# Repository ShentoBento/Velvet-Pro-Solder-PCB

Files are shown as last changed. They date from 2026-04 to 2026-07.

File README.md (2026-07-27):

# Velvet Pro Solder PCB

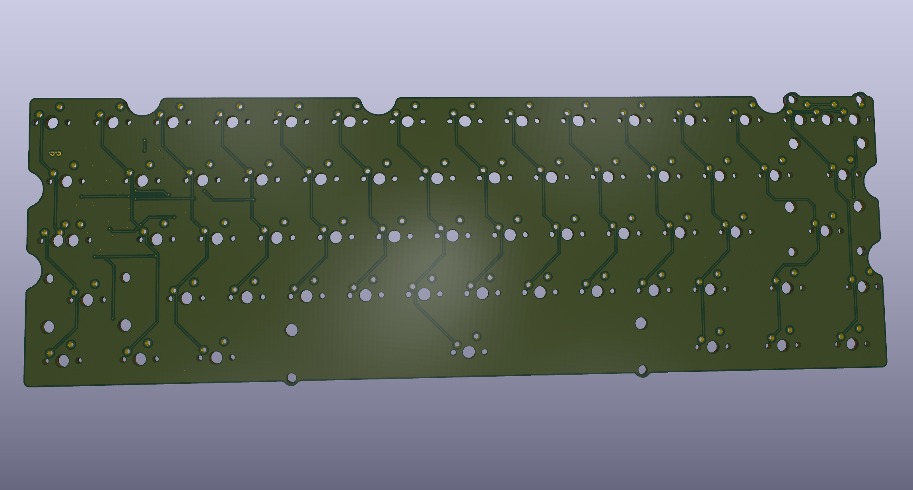
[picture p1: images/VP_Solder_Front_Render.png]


A solder PCB designed to fit the Velvet Pro keyboard by Ampersandy.

Firmware: https://github.com/ShentoBento/Velvet-Pro-PCB-Firmware

---

## Specs

- Solder
- MCU: STM32F072CBTx
- JST SH 4-pin connector (for C3 Unified Daughterboards)
- Fixed ANSI enter
- Fixed 7u bottom row
- Fixed split right shift
- Stepped or full caps lock
- Split or full backspace
- VIA and Vial compatible (via the firmware linked above)

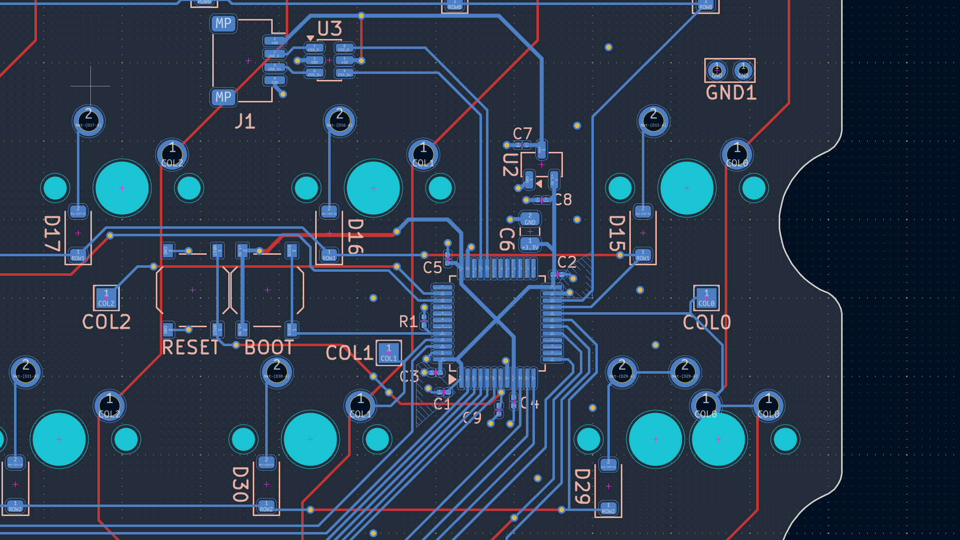
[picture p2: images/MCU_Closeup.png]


---

## Requirements

- **KiCad 10** or newer. Earlier versions will not open these files.
- Nothing else. All symbols, footprints, and 3D models used by this project are
  included in this repo — no external libraries to install, no PCM packages,
  no library paths to configure.

---

## Opening the project

1. Clone or download this repo.
2. Open `VP_Solder_KiCad/VP_Solder.kicad_pro` in KiCad.

The library paths are stored relative to the project folder, so the repo works
from any location on any operating system. If KiCad reports missing symbols or
footprints, the most likely cause is that the `shentobento_kicad_library/`
folder was not cloned alongside `VP_Solder_KiCad/`.

---

## What's in this repo

### `VP_Solder_KiCad/`

The KiCad project. These are the files you edit.

| File | What it is |
|---|---|
| `VP_Solder.kicad_pro` | Project file — **open this one** |
| `VP_Solder.kicad_sch` | Schematic |
| `VP_Solder.kicad_pcb` | Board layout |
| `fp-lib-table`, `sym-lib-table` | Point KiCad at the bundled library |
| `fabrication-toolkit-options.json` | Settings for the JLCPCB fabrication plugin |

### `VP_Solder_KiCad/production/`

Ready-to-order manufacturing files, generated with the JLCPCB Fabrication Toolkit plugin.

| File | Upload it to |
|---|---|
| `VP_Solder.zip` | JLCPCB's gerber upload — this is the board itself |
| `bom.csv` | Assembly service (which parts) |
| `positions.csv` | Assembly service (where they go) |

If you modify the design, **regenerate these** rather than reusing them. Stale
production files that don't match the current board are how wrong PCBs get
manufactured.

### `shentobento_kicad_library/`

Every symbol and footprint this project uses, in one place.

- `shentobento.kicad_sym` — all symbols
- `shentobento.pretty/` — all footprints
- `3dmodels/` — 3D models for the parts that need them

Symbols come with their footprints pre-assigned, so dragging a part into a
schematic gives you a working part with no footprint assignment step.

This folder is self-contained and can be copied into other keyboard projects.

### `reference files and images`

Not needed to build the board — useful if you're modifying the layout.

- `Plate_File_No_Flex_Cuts.dxf` / `Plate_File_with_Flex_Cuts.dxf` — the official
  Velvet Pro plate files, used to align switch and stabilizer positions
- `VP PCB DXF.dxf` — the official board outline, thanks to Andykit
- Various images of the PCB and schematic

---

## Credits and licenses

Keyboard footprints and symbols are derived from
[marbastlib](https://github.com/ebastler/marbastlib) by ebastler, licensed under
CERN-OHL-P v2. See `shentobento_kicad_library/LICENSE-marbastlib.txt`.

Generic footprints (passives, SOT-23, LQFP-48, JST SH, test points) are copied
from the KiCad standard libraries.

Modifications made to third-party files are recorded in
`shentobento_kicad_library/NOTICE.md`.

The Velvet Pro case and plate files are the work of Ampersandy.

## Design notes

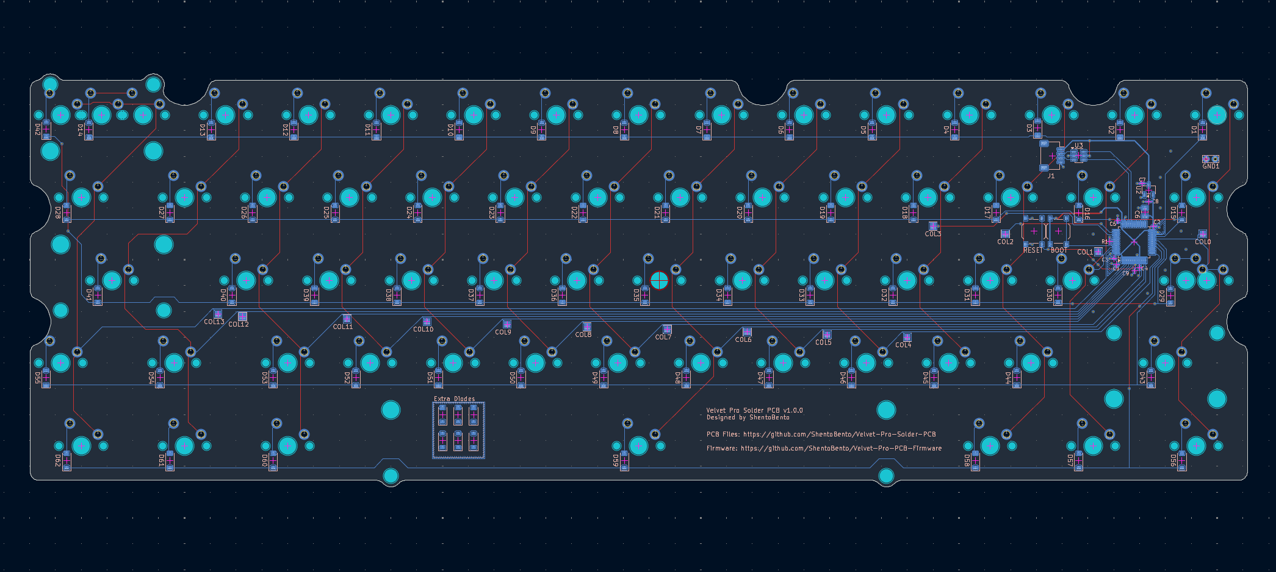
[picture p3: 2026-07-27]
images/Back_2.png

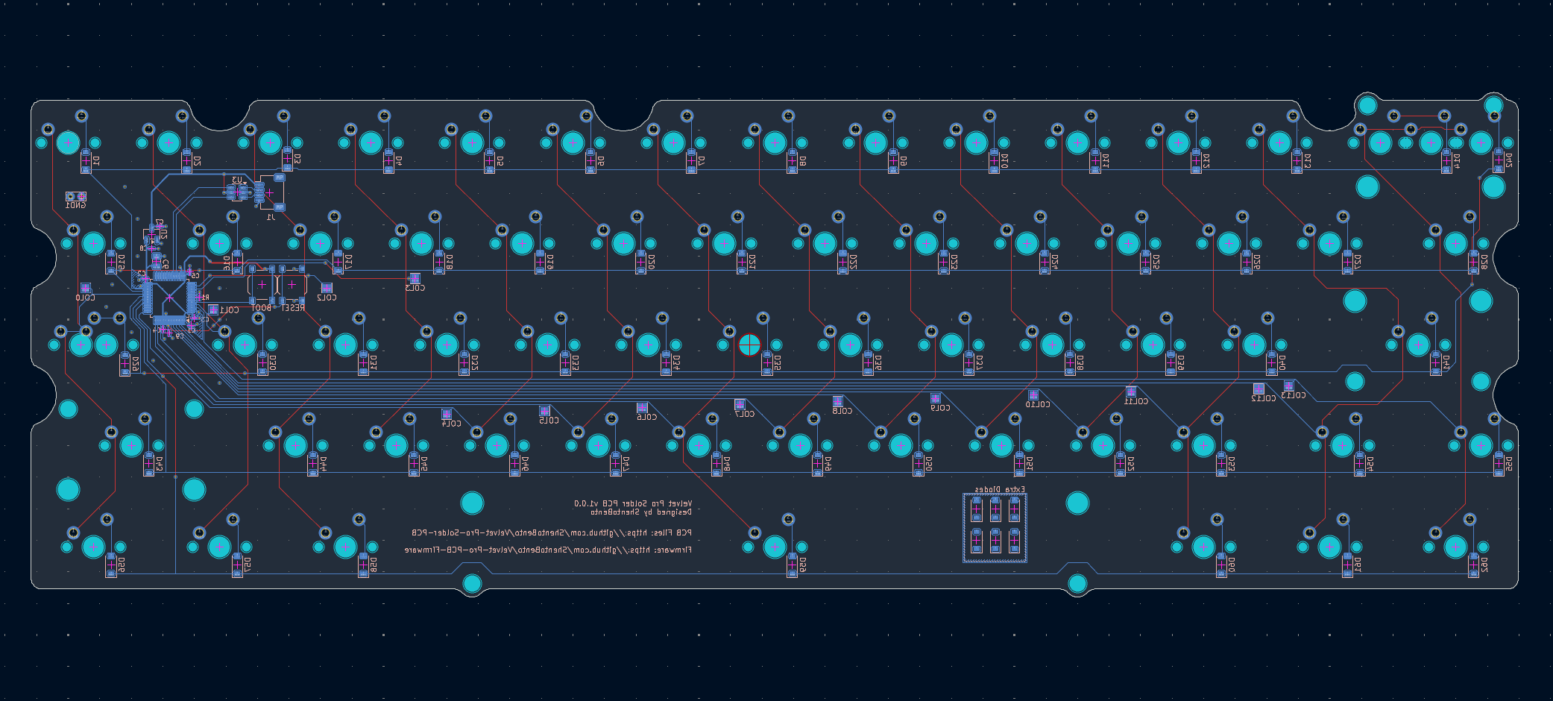
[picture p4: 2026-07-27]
images/Front_2.png

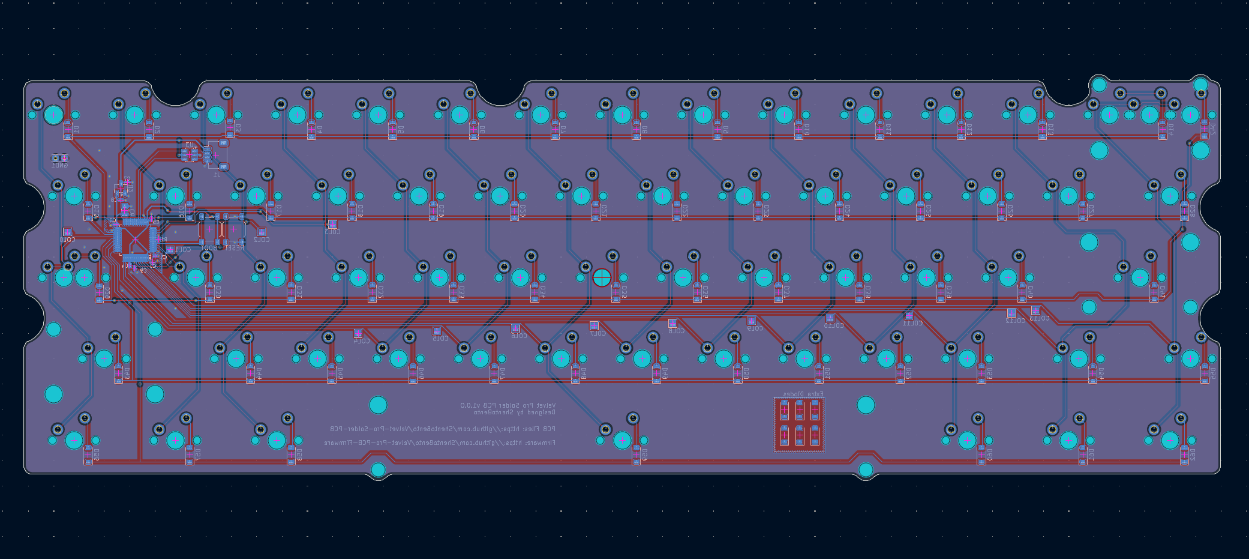
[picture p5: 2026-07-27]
images/Front_1.png

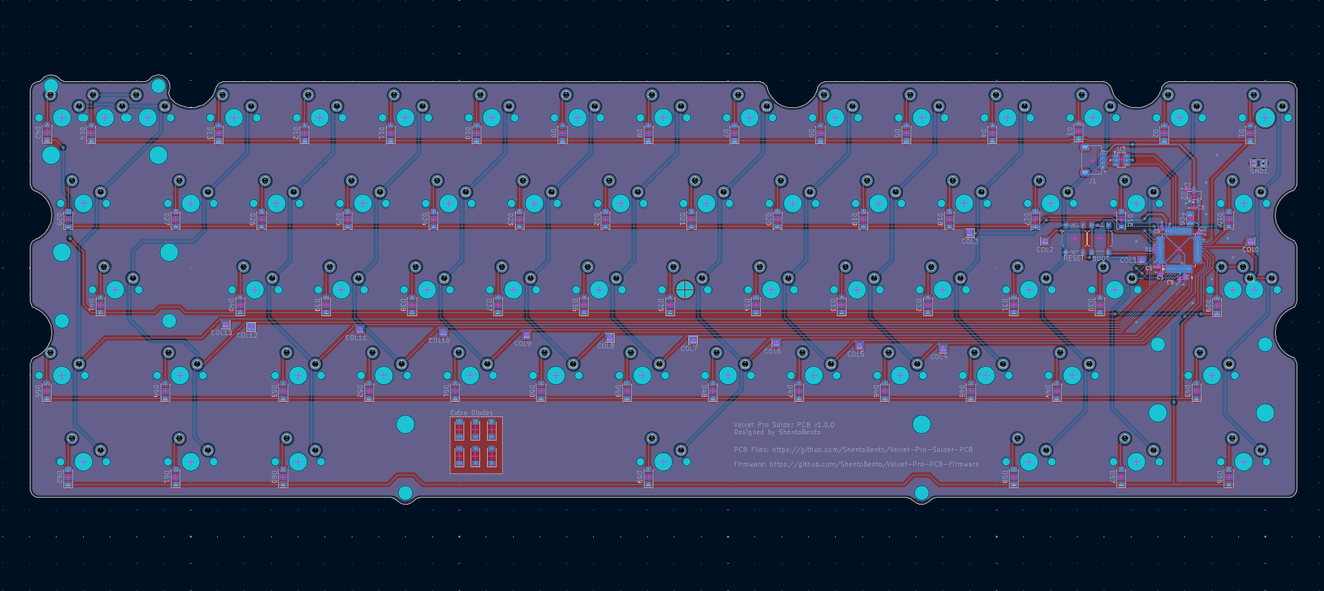
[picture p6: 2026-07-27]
images/Back_1.png

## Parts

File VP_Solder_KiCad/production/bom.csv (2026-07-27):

Designator | Footprint | Quantity | Value | LCSC Part #
C1, C2, C3, C4, C5 | 0201 | 5 | 100nF
C6 | 0805 | 1 | 10uF
C7, C8 | 0201 | 2 | 1uF
C9 | 0201 | 1 | 0.1uF
COL0, COL1, COL10, COL11, COL12, COL13, COL2, COL3, COL4, COL5, COL6, COL7, COL8, COL9 | TestPoint_Pad_1.5x1.5mm | 14 | TestPoint
D1, D10, D11, D12, D13, D14, D15, D16, D17, D18, D19, D2, D20, D21, D22, D23, D24, D25, D26, D27, D28, D29, D3, D30, D31, D32, D33, D34, D35, D36, D37, D38, D39, D4, D40, D41, D42, D43, D44, D45, D46, D47, D48, D49, D5, D50, D51, D52, D53, D54, D55, D56, D57, D58, D59, D6, D60, D61, D62, D63, D64, D65, D66, D67, D68, D7, D8, D9 | D_SOD-123 | 68 | 1N4148
GND1 | TestPoint_Bridge_Pitch2.0mm_Drill0.7mm | 1 | TestPoint
J1 | JST_SH_1x04 | 1 | Conn_01x04
KC_0, KC_1, KC_2, KC_3, KC_4, KC_5, KC_6, KC_7, KC_8, KC_9, KC_A1, KC_B1, KC_BKSP1, KC_BKSP2, KC_BSLS2, KC_C1, KC_COMM1, KC_D1, KC_DOT1, KC_E1, KC_ENT1, KC_EQL1, KC_ESC1, KC_F1, KC_G1, KC_H1, KC_I1, KC_J1, KC_K1, KC_L1, KC_LBRC1, KC_LGUI1, KC_LSFT1, KC_M1, KC_MINS1, KC_MO1, KC_N1, KC_O1, KC_P1, KC_Q1, KC_QUOT1, KC_R1, KC_RBRC1, KC_RGUI1, KC_RSFT1, KC_S1, KC_SCLN1, KC_SLSH1, KC_SPC1, KC_T1, KC_U1, KC_V1, KC_W1, KC_X1, KC_Y1, KC_Z1 | SW_MX_1u | 56 | MX_SW_solder
KC_BSLS1, KC_LALT1, KC_LCTL1, KC_RALT1, KC_RCTL1, KC_TAB1 | SW_MX_1.5u | 6 | MX_SW_solder
KC_CAPS1 | SW_MX_1.75u | 1 | MX_SW_solder
KC_STEP1 | SW_MX_1.75u_STEPPED_1.25 | 1 | MX_SW_solder
R1 | 0201 | 1 | 10k
SW1, SW2 | SW_Push_Reset_Bootloader | 2 | SW_Push
U1 | MCU_STM32F072CBTx | 1 | STM32F072CBTx
U2 | SOT-23-3 | 1 | XC6206PxxxMR
U3 | SOT-23-6 | 1 | USBLC6-2SC6

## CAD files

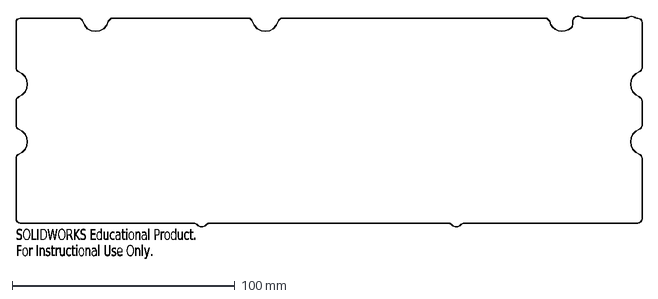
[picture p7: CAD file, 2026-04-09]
Other files (mainly for reference)/Velvet_Pro_PCB_outline.DXF
SOLIDWORKS Educational Product.
For Instructional Use Only.

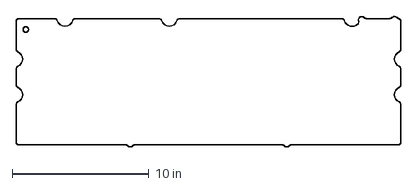
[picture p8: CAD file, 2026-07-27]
reference/Velvet_Pro_PCB_outline.dxf
28.1 x 9.55 in

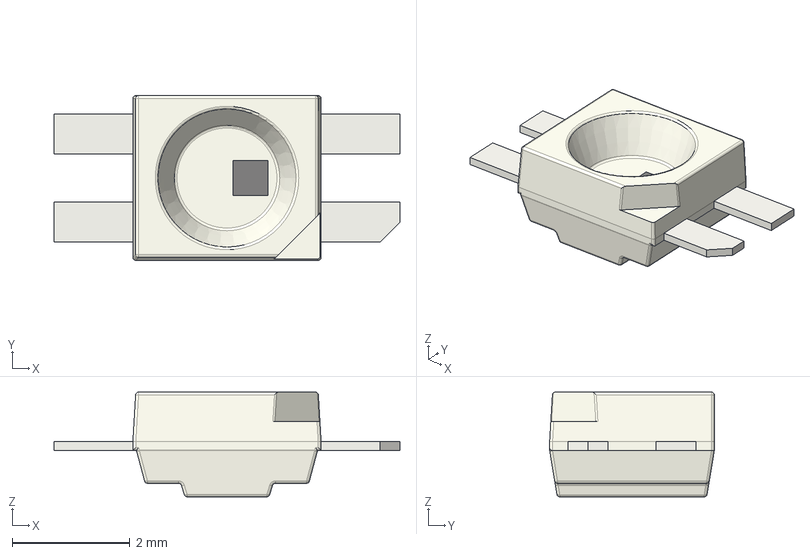
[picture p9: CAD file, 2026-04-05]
shentobento_kicad_library/3dmodels/LED_SK6812MINI-E.step
5.88 x 2.80 x 1.78 mm

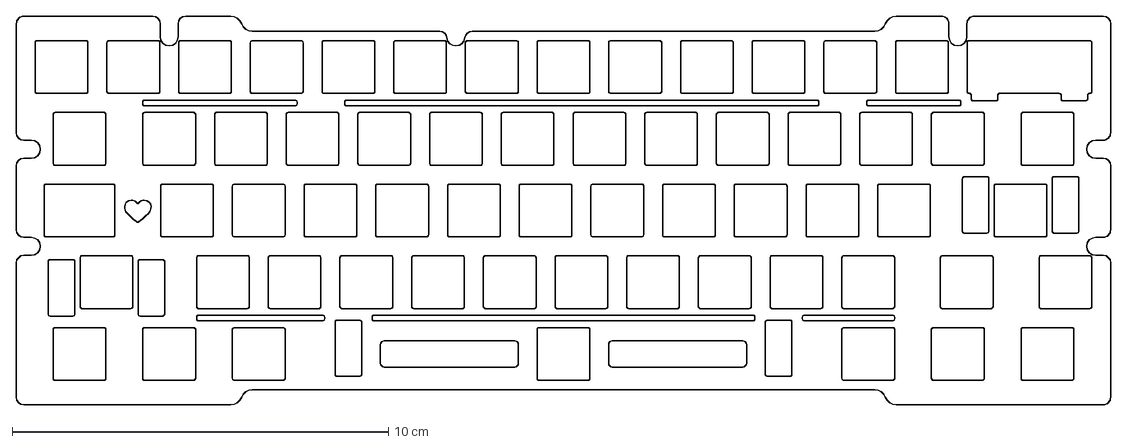
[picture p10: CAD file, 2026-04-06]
reference/Plate_File_with_Flex_Cuts.dxf
29.1 x 10.3 cm

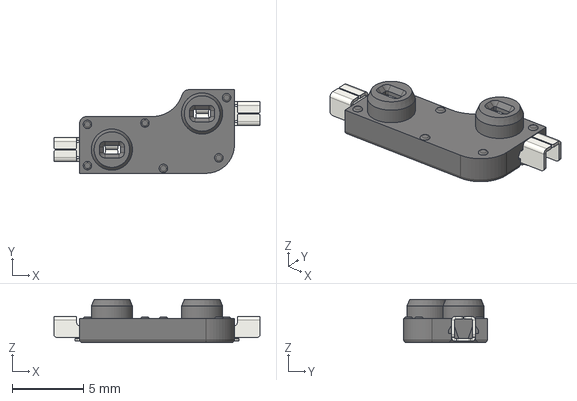
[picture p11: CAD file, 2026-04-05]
shentobento_kicad_library/3dmodels/HS_CPG151101S11_MX.step
14.5 x 5.89 x 3.05 mm
Contact x 2

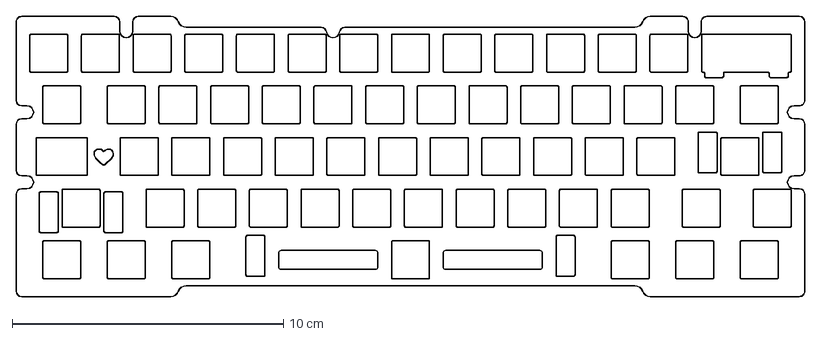
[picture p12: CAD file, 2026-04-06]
reference/Plate_File_No_Flex_Cuts.dxf
29.1 x 10.3 cm

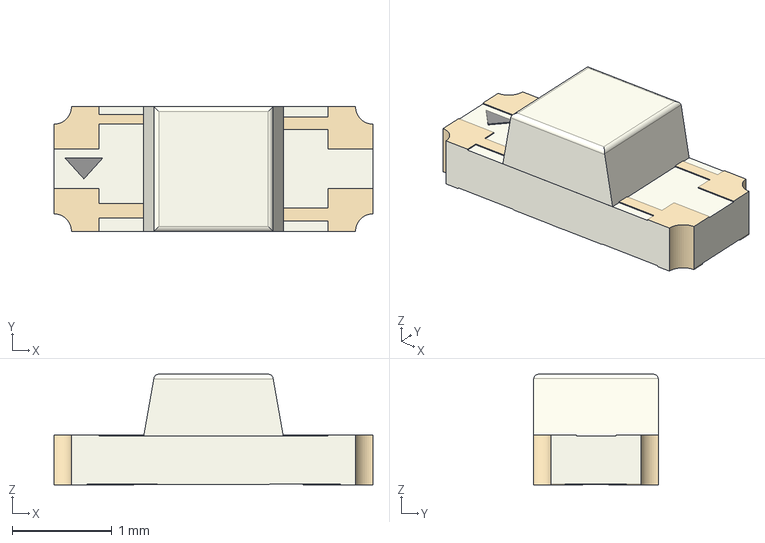
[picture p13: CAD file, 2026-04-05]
shentobento_kicad_library/3dmodels/LED_MHT151RGBCT.step
3.20 x 1.25 x 1.11 mm

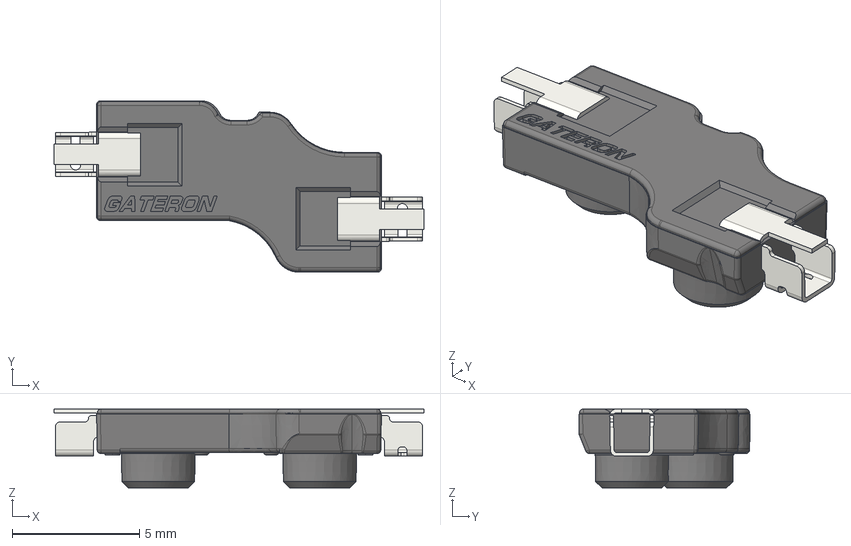
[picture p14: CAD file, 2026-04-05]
shentobento_kicad_library/3dmodels/HS_KS-2P02B01-01_MX.step
14.6 x 6.74 x 3.10 mm

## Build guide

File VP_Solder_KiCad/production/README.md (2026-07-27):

# How to order this PCB from JLCPCB

You do **not** need KiCad for this. Everything you need is in
`VP_Solder_KiCad/production/`.

---

## What you need

| File | What it's for |
|---|---|
| `VP_Solder.zip` | The board itself. Required. |
| `bom.csv` | Which parts to solder on. Only needed for assembly. |
| `positions.csv` | Where those parts go. Only needed for assembly. |

---

## Ordering from JLCPCB with Assembly

**Estimated Costs:** $20-30/PCB shipped to US (tariffs included)
**Fullfillment Time:** Around 2-3 weeks

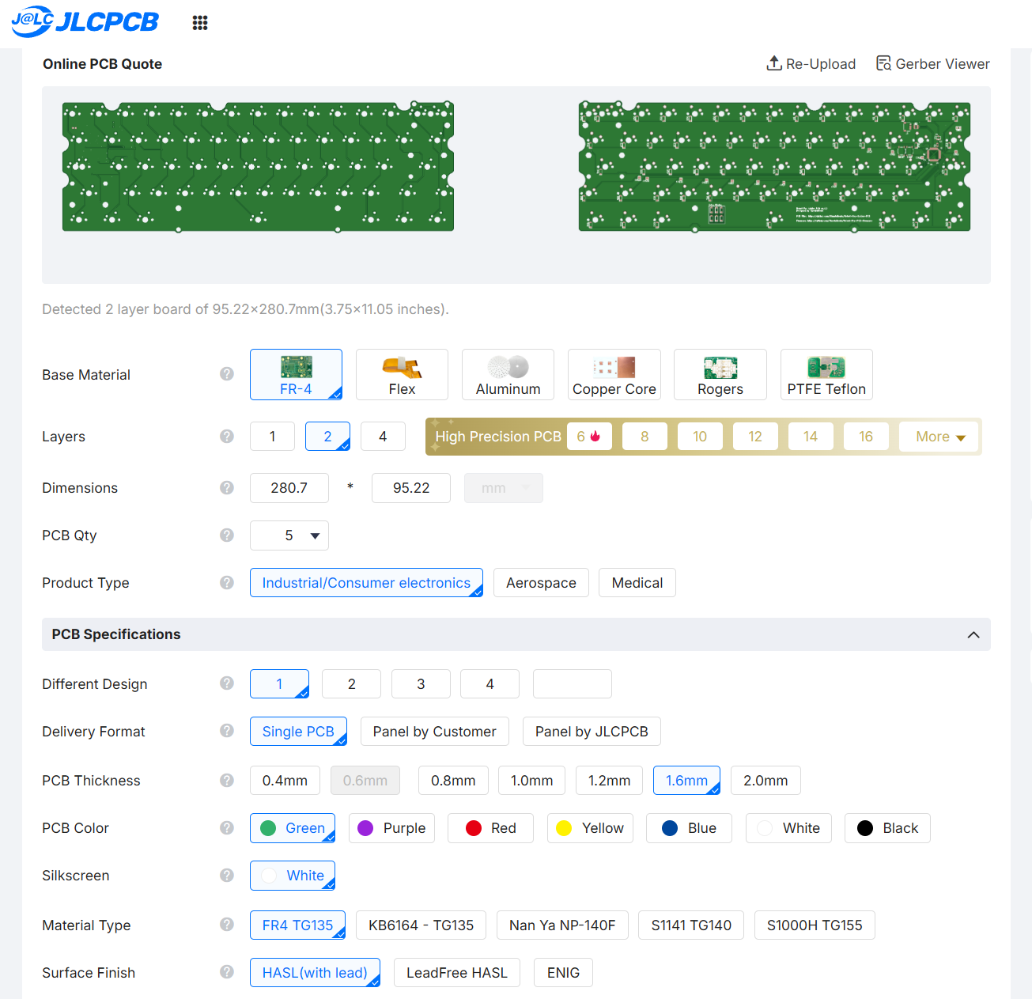
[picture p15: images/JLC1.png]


1. Go to [jlcpcb.com](https://jlcpcb.com), click order, and then **Add gerber file**.
2. Upload `VP_Solder.zip`.
3. Wait for the preview to load, then check it against the images in this
   repo's README. The board outline should match.
4. Leave the defaults alone unless you want a specific colour. The defaults
   (1.6mm thickness, HASL, 2 layers, FR4) are correct for this board. 1.2mm
   also works but you will need stabilizer shims. Don't change anything in the
   **High-Spec Options** section.
5. Toggle **PCB Assembly** on. Choose **Assemble bottom side**. You will need to
   choose the **Standard** PCBA option, keep other options as default
   (Parts Selection by customer, OPTIONAL: Confirm parts placement).
6. CLick **Save to Cart** and you will see a preview of the PCB, click next, and
   upload `bom.csv` when asked for the BOM and `positions.csv` when asked for the
   CPL / pick-and-place file. Then click **Process BOM & CPL**.
7. JLCPCB will attempt to match your parts from the BOM to parts in stock. Some parts
   will be unmatched. Check each part to match to the JLC part in this table:

| Designators | Value | Package | JLCPCB part ID | Alternative JLCPCB Part ID's |
| --- | --- | --- | --- | --- |
| C1–C5, C9 | 100 nF | 0201 | C76934 | C76938, C66938, C76928, C49062 |
| C6 | 10 µF | 0805 | C440198 | C15850, C1713, C40894 |
| C7, C8 | 1 µF | 0201 | C76935 | C53067, C87143, C76930 |
| D1–D62 | 1N4148W | **SOD-123** | C81598 | C84367, C83528 |
| R1 | 10 kΩ | 0201 | C7467266 | C106225, C138117, C102684 |
| U1 | STM32F072CBT6 | LQFP-48 | C81720 | - |
| U2 | XC6206P332MR | SOT-23-3 | C5446 | - |
| U3 | USBLC6-2SC6 | SOT-23-6 | C2827654 | - |
| SW1, SW2 | TS-1187A-B-A-B | SMD tactile | C318884 | - |
| J1 | SM04B-SRSS-TB | JST SH 4-pin | C160404 | - |

**Please note:**
- The MCU uses the **CB** variant **STM32F072CBT6** (128 KB flash), not **C8**
(64 KB).
- Leave Test points and GND1 as unmatched.
- Some parts in this table might be out of stock when you check.
  Just choose from the alternative column.

8. After clicking **Next** you are then asked to confirm component placements.
   Sometimes JLC will incorrectly rotate a part, so this is an important step.
   Review the component placement preview. Check that the diodes' positive end
   faces **UP**. Make sure each components' purple dot is lined up with the triangle
   on the pcb. Make sure to verify **U2** is in the correct orientation, JLC
   likes flipping that one 90 degrees. As you can see here, U1 is in the incorrect orientation:

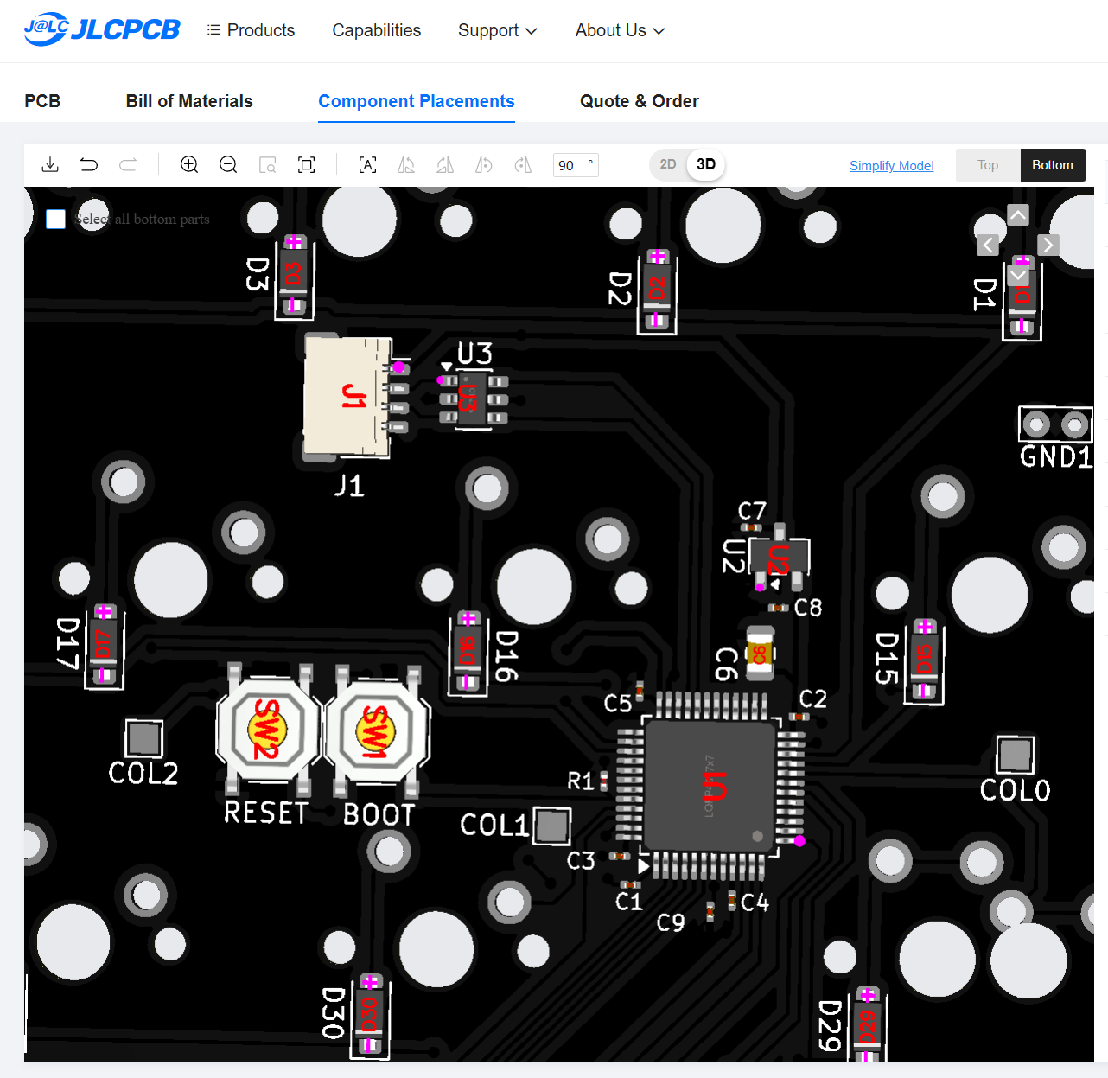
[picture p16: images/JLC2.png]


9. At the last stage, set your product description as **Office Applicance and Accessories** -> **Keyboard HS Code 847330**

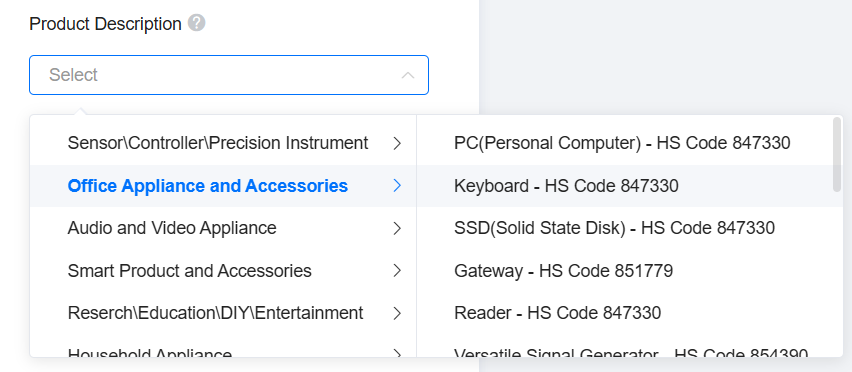
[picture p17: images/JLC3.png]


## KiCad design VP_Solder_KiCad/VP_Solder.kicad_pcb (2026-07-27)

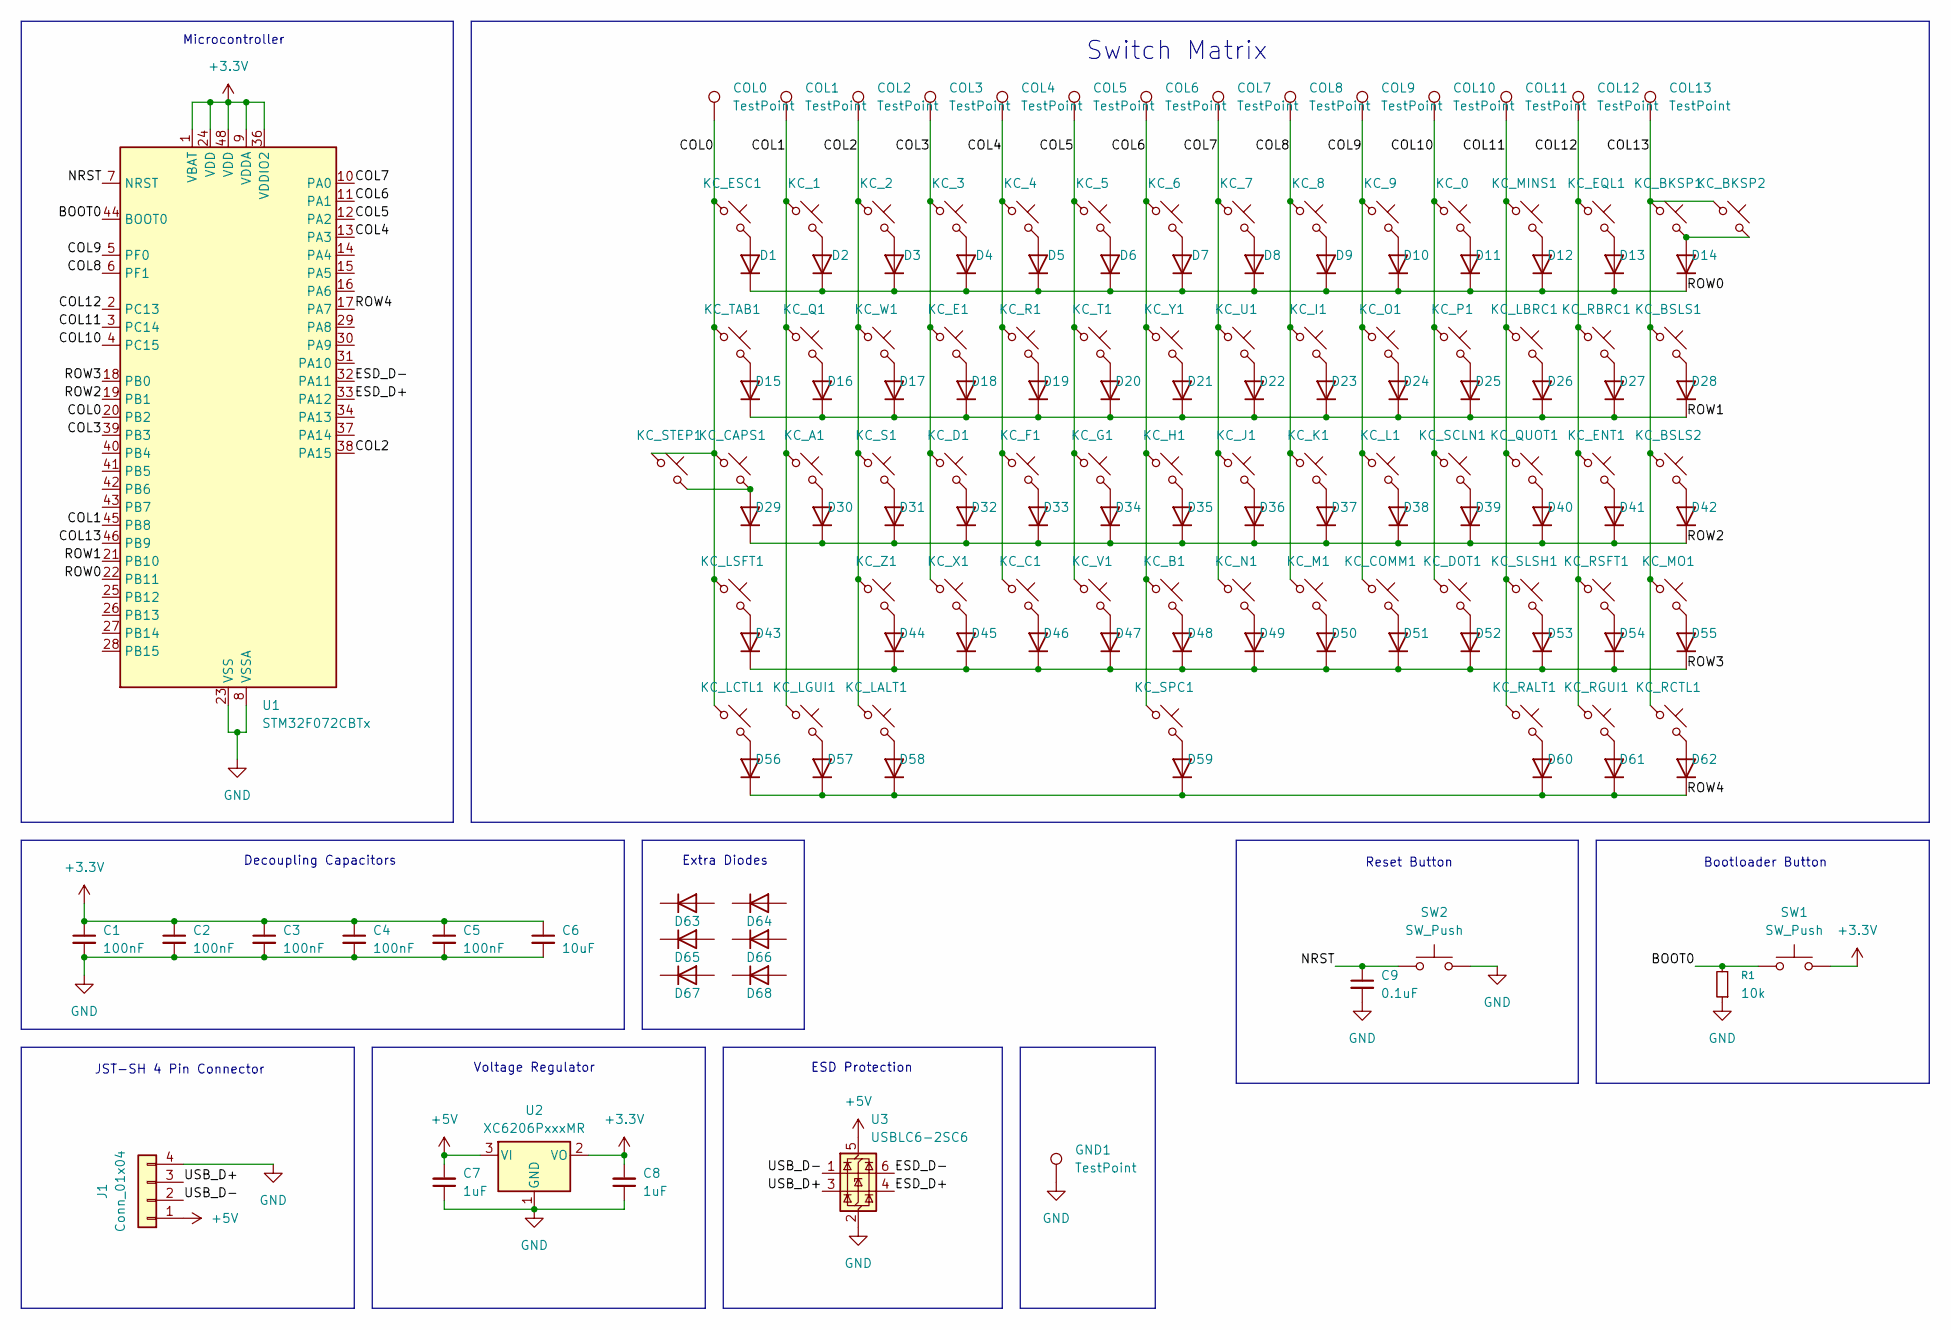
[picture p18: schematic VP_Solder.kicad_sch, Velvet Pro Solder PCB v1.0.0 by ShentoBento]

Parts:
C1, C2, C3, C4, C5: 100nF; C_0201_0603Metric
C6: 10uF; C_0805_2012Metric
C7, C8: 1uF; C_0201_0603Metric
C9: 0.1uF; C_0201_0603Metric
COL0, COL1, COL2, COL3, COL4, COL5, COL6, COL7, COL8, COL9, COL10, COL11, COL12, COL13: TestPoint; TestPoint_Pad_1.5x1.5mm
D1, D2, D3, D4, D5, D6, D7, D8, D9, D10, D11, D12, D13, D14, D15, D16, D17, D18, D19, D20, D21, D22, D23, D24, D25, D26, D27, D28, D29, D30, D31, D32, D33, D34, D35, D36, D37, D38, D39, D40, D41, D42, D43, D44, D45, D46, D47, D48, D49, D50, D51, D52, D53, D54, D55, D56, D57, D58, D59, D60, D61, D62, D63, D64, D65, D66, D67, D68: 1N4148; D_SOD-123
GND1: TestPoint; TestPoint_Bridge_Pitch2.0mm_Drill0.7mm
J1: Conn_01x04; JST_SH_1x04
KC_0, KC_1, KC_2, KC_3, KC_4, KC_5, KC_6, KC_7, KC_8, KC_9: MX_SW_solder; SW_MX_1u
KC_A1: MX_SW_solder; SW_MX_1u
KC_B1: MX_SW_solder; SW_MX_1u
KC_BKSP1, KC_BKSP2: MX_SW_solder; SW_MX_1u
KC_BSLS1: MX_SW_solder; SW_MX_1.5u
KC_BSLS2: MX_SW_solder; SW_MX_1u
KC_C1: MX_SW_solder; SW_MX_1u
KC_CAPS1: MX_SW_solder; SW_MX_1.75u
KC_COMM1: MX_SW_solder; SW_MX_1u
KC_D1: MX_SW_solder; SW_MX_1u
KC_DOT1: MX_SW_solder; SW_MX_1u
KC_E1: MX_SW_solder; SW_MX_1u
KC_ENT1: MX_SW_solder; SW_MX_1u
KC_EQL1: MX_SW_solder; SW_MX_1u
KC_ESC1: MX_SW_solder; SW_MX_1u
KC_F1: MX_SW_solder; SW_MX_1u
KC_G1: MX_SW_solder; SW_MX_1u
KC_H1: MX_SW_solder; SW_MX_1u
KC_I1: MX_SW_solder; SW_MX_1u
KC_J1: MX_SW_solder; SW_MX_1u
KC_K1: MX_SW_solder; SW_MX_1u
KC_L1: MX_SW_solder; SW_MX_1u
KC_LALT1: MX_SW_solder; SW_MX_1.5u
KC_LBRC1: MX_SW_solder; SW_MX_1u
KC_LCTL1: MX_SW_solder; SW_MX_1.5u
KC_LGUI1: MX_SW_solder; SW_MX_1u
KC_LSFT1: MX_SW_solder; SW_MX_1u
KC_M1: MX_SW_solder; SW_MX_1u
KC_MINS1: MX_SW_solder; SW_MX_1u
KC_MO1: MX_SW_solder; SW_MX_1u
KC_N1: MX_SW_solder; SW_MX_1u
KC_O1: MX_SW_solder; SW_MX_1u
KC_P1: MX_SW_solder; SW_MX_1u
KC_Q1: MX_SW_solder; SW_MX_1u
KC_QUOT1: MX_SW_solder; SW_MX_1u
KC_R1: MX_SW_solder; SW_MX_1u
KC_RALT1: MX_SW_solder; SW_MX_1.5u
KC_RBRC1: MX_SW_solder; SW_MX_1u
KC_RCTL1: MX_SW_solder; SW_MX_1.5u
KC_RGUI1: MX_SW_solder; SW_MX_1u
KC_RSFT1: MX_SW_solder; SW_MX_1u
KC_S1: MX_SW_solder; SW_MX_1u
KC_SCLN1: MX_SW_solder; SW_MX_1u
KC_SLSH1: MX_SW_solder; SW_MX_1u
KC_SPC1: MX_SW_solder; SW_MX_1u
KC_STEP1: MX_SW_solder; SW_MX_1.75u_STEPPED_1.25
KC_T1: MX_SW_solder; SW_MX_1u
KC_TAB1: MX_SW_solder; SW_MX_1.5u
KC_U1: MX_SW_solder; SW_MX_1u
KC_V1: MX_SW_solder; SW_MX_1u
KC_W1: MX_SW_solder; SW_MX_1u
KC_X1: MX_SW_solder; SW_MX_1u
KC_Y1: MX_SW_solder; SW_MX_1u
KC_Z1: MX_SW_solder; SW_MX_1u
R1: 10k; R_0201_0603Metric
SW1, SW2: SW_Push; SW_Push_Reset_Bootloader
U1: STM32F072CBTx; MCU_STM32F072CBTx
U2: XC6206PxxxMR; SOT-23-3
U3: USBLC6-2SC6; SOT-23-6

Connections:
+3.3V: C1.1, C2.1, C3.1, C4.1, C5.1, C6.1, C8.2, SW1.2, U1.1 (VBAT), U1.9 (VDDA), U1.24 (VDD), U1.36 (VDDIO2), U1.48 (VDD), U2.2 (VO)
+5V: C7.2, J1.1, U2.3 (VI), U3.5 (VBUS)
/BOOT0: R1.2, SW1.1, U1.44 (BOOT0)
/COL0: COL0.1 (1_1), KC_CAPS1.1, KC_ESC1.1, KC_LCTL1.1, KC_LSFT1.1, KC_STEP1.1, KC_TAB1.1, U1.20 (PB2)
/COL1: COL1.1 (1_1), KC_1.1, KC_A1.1, KC_LGUI1.1, KC_Q1.1, U1.45 (PB8)
/COL2: COL2.1 (1_1), KC_2.1, KC_LALT1.1, KC_S1.1, KC_W1.1, KC_Z1.1, U1.38 (PA15)
/COL3: COL3.1 (1_1), KC_3.1, KC_D1.1, KC_E1.1, KC_X1.1, U1.39 (PB3)
/COL4: COL4.1 (1_1), KC_4.1, KC_C1.1, KC_F1.1, KC_R1.1, U1.13 (PA3)
/COL5: COL5.1 (1_1), KC_5.1, KC_G1.1, KC_T1.1, KC_V1.1, U1.12 (PA2)
/COL6: COL6.1 (1_1), KC_6.1, KC_B1.1, KC_H1.1, KC_SPC1.1, KC_Y1.1, U1.11 (PA1)
/COL7: COL7.1 (1_1), KC_7.1, KC_J1.1, KC_N1.1, KC_U1.1, U1.10 (PA0)
/COL8: COL8.1 (1_1), KC_8.1, KC_I1.1, KC_K1.1, KC_M1.1, U1.6 (PF1)
/COL9: COL9.1 (1_1), KC_9.1, KC_COMM1.1, KC_L1.1, KC_O1.1, U1.5 (PF0)
/COL10: COL10.1 (1_1), KC_0.1, KC_DOT1.1, KC_P1.1, KC_SCLN1.1, U1.4 (PC15)
/COL11: COL11.1 (1_1), KC_LBRC1.1, KC_MINS1.1, KC_QUOT1.1, KC_RALT1.1, KC_SLSH1.1, U1.3 (PC14)
/COL12: COL12.1 (1_1), KC_ENT1.1, KC_EQL1.1, KC_RBRC1.1, KC_RGUI1.1, KC_RSFT1.1, U1.2 (PC13)
/COL13: COL13.1 (1_1), KC_BKSP1.1, KC_BKSP2.1, KC_BSLS1.1, KC_BSLS2.1, KC_MO1.1, KC_RCTL1.1, U1.46 (PB9)
/ESD_D+: U1.33 (PA12), U3.4 (I/O2)
/ESD_D-: U1.32 (PA11), U3.6 (I/O1)
/NRST: C9.1, SW2.1, U1.7 (NRST)
/ROW0: D1.1 (K), D2.1 (K), D3.1 (K), D4.1 (K), D5.1 (K), D6.1 (K), D7.1 (K), D8.1 (K), D9.1 (K), D10.1 (K), D11.1 (K), D12.1 (K), D13.1 (K), D14.1 (K), U1.22 (PB11)
/ROW1: D15.1 (K), D16.1 (K), D17.1 (K), D18.1 (K), D19.1 (K), D20.1 (K), D21.1 (K), D22.1 (K), D23.1 (K), D24.1 (K), D25.1 (K), D26.1 (K), D27.1 (K), D28.1 (K), U1.21 (PB10)
/ROW2: D29.1 (K), D30.1 (K), D31.1 (K), D32.1 (K), D33.1 (K), D34.1 (K), D35.1 (K), D36.1 (K), D37.1 (K), D38.1 (K), D39.1 (K), D40.1 (K), D41.1 (K), D42.1 (K), U1.19 (PB1)
/ROW3: D43.1 (K), D44.1 (K), D45.1 (K), D46.1 (K), D47.1 (K), D48.1 (K), D49.1 (K), D50.1 (K), D51.1 (K), D52.1 (K), D53.1 (K), D54.1 (K), D55.1 (K), U1.18 (PB0)
/ROW4: D56.1 (K), D57.1 (K), D58.1 (K), D59.1 (K), D60.1 (K), D61.1 (K), D62.1 (K), U1.17 (PA7)
/USB_D+: J1.3, U3.3 (I/O2)
/USB_D-: J1.2, U3.1 (I/O1)
GND: C1.2, C2.2, C3.2, C4.2, C5.2, C6.2, C7.1, C8.1, C9.2, GND1.1 (1_1), J1.4, R1.1, SW2.2, U1.8 (VSSA), U1.23 (VSS), U1.35 (VSS), U1.47 (VSS), U2.1 (GND), U3.2 (GND)
unnamed: D1.2 (A), KC_ESC1.2
unnamed: D2.2 (A), KC_1.2
unnamed: D3.2 (A), KC_2.2
unnamed: D4.2 (A), KC_3.2
unnamed: D5.2 (A), KC_4.2
unnamed: D6.2 (A), KC_5.2
unnamed: D7.2 (A), KC_6.2
unnamed: D8.2 (A), KC_7.2
unnamed: D9.2 (A), KC_8.2
unnamed: D10.2 (A), KC_9.2
unnamed: D11.2 (A), KC_0.2
unnamed: D12.2 (A), KC_MINS1.2
unnamed: D13.2 (A), KC_EQL1.2
unnamed: D14.2 (A), KC_BKSP1.2, KC_BKSP2.2
unnamed: D15.2 (A), KC_TAB1.2
unnamed: D16.2 (A), KC_Q1.2
unnamed: D17.2 (A), KC_W1.2
unnamed: D18.2 (A), KC_E1.2
unnamed: D19.2 (A), KC_R1.2
unnamed: D20.2 (A), KC_T1.2
unnamed: D21.2 (A), KC_Y1.2
unnamed: D22.2 (A), KC_U1.2
unnamed: D23.2 (A), KC_I1.2
unnamed: D24.2 (A), KC_O1.2
unnamed: D25.2 (A), KC_P1.2
unnamed: D26.2 (A), KC_LBRC1.2
unnamed: D27.2 (A), KC_RBRC1.2
unnamed: D28.2 (A), KC_BSLS1.2
unnamed: D29.2 (A), KC_CAPS1.2, KC_STEP1.2
unnamed: D30.2 (A), KC_A1.2
unnamed: D31.2 (A), KC_S1.2
unnamed: D32.2 (A), KC_D1.2
unnamed: D33.2 (A), KC_F1.2
unnamed: D34.2 (A), KC_G1.2
unnamed: D35.2 (A), KC_H1.2
unnamed: D36.2 (A), KC_J1.2
unnamed: D37.2 (A), KC_K1.2
unnamed: D38.2 (A), KC_L1.2
unnamed: D39.2 (A), KC_SCLN1.2
unnamed: D40.2 (A), KC_QUOT1.2
unnamed: D41.2 (A), KC_ENT1.2
unnamed: D42.2 (A), KC_BSLS2.2
unnamed: D43.2 (A), KC_LSFT1.2
unnamed: D44.2 (A), KC_Z1.2
unnamed: D45.2 (A), KC_X1.2
unnamed: D46.2 (A), KC_C1.2
unnamed: D47.2 (A), KC_V1.2
unnamed: D48.2 (A), KC_B1.2
unnamed: D49.2 (A), KC_N1.2
unnamed: D50.2 (A), KC_M1.2
unnamed: D51.2 (A), KC_COMM1.2
unnamed: D52.2 (A), KC_DOT1.2
unnamed: D53.2 (A), KC_SLSH1.2
unnamed: D54.2 (A), KC_RSFT1.2
unnamed: D55.2 (A), KC_MO1.2
unnamed: D56.2 (A), KC_LCTL1.2
unnamed: D57.2 (A), KC_LGUI1.2
unnamed: D58.2 (A), KC_LALT1.2
unnamed: D59.2 (A), KC_SPC1.2
unnamed: D60.2 (A), KC_RALT1.2
unnamed: D61.2 (A), KC_RGUI1.2
unnamed: D62.2 (A), KC_RCTL1.2

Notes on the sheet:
Reset Button
Microcontroller
Voltage Regulator
Extra Diodes
JST-SH 4 Pin Connector
Bootloader Button
ESD Protection
Decoupling Capacitors
Switch Matrix

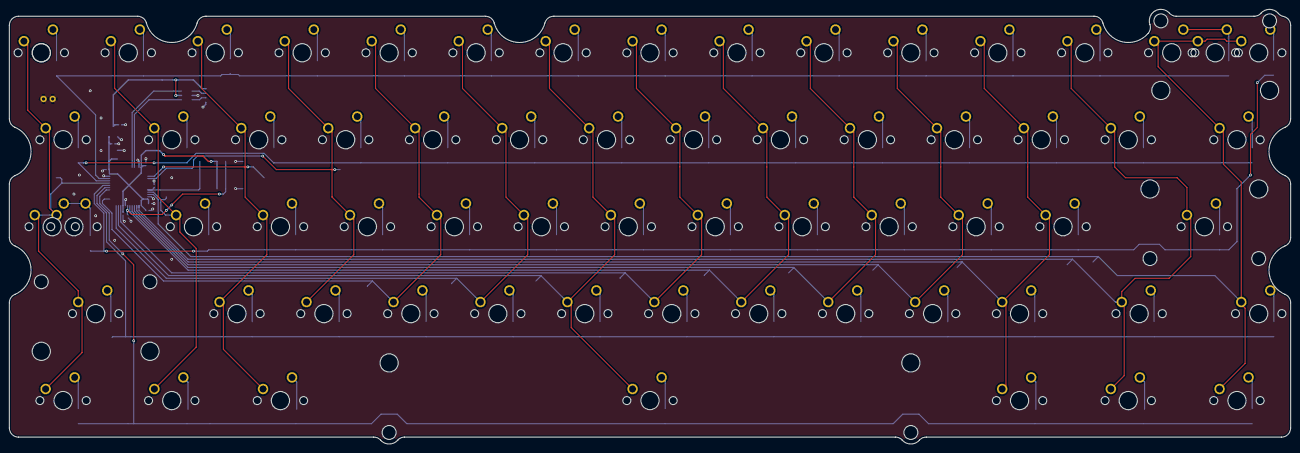
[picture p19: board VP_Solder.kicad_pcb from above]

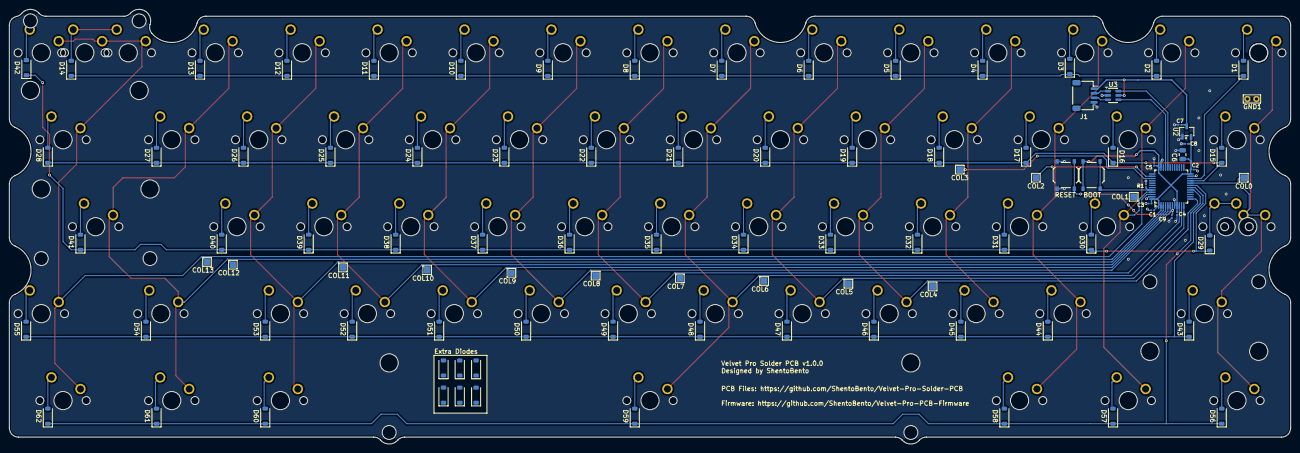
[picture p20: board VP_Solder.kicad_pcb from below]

Board: 2 copper layers, 280.7 x 95.2 mm, 163 parts (99 on the bottom side), 90 nets.

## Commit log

2026-04-05 Initial KiCad project files
    [bb60_v1.kicad_pcb, bb60_v1.kicad_sch]
2026-04-05 Add marbastlib external KiCad libraries
2026-04-05 Migrate to KiCad 10 and save symbol library paths
2026-04-05 added microcontroller, decoupling capacitors
    [bb60_v1.kicad_sch]
2026-04-06 added voltage regulator, jst connector, matrix
    voltage regular and matrix are unfinished
    [bb60_v1.kicad_sch]
2026-04-06 Visual changes to schematic
    [bb60_v1.kicad_sch]
2026-04-06 Added USB Resistors, ESD Protection, Reset and bootloader buttons
    [bb60_v1.kicad_sch]
2026-04-06 Small changes to schematic
    [bb60_v1.kicad_sch]
2026-04-06 PCB Layout Rough Draft
    [bb60_v1.kicad_pcb, bb60_v1.kicad_sch]
2026-04-06 Fixed stab keys on pcb
    [bb60_v1.kicad_pcb, bb60_v1.kicad_sch]
2026-04-06 added vp plate files
    [Plate_File_No_Flex_Cuts (1).dxf, Plate_File_with_Flex_Cuts (1).dxf]
2026-04-06 Added row/column traces
    [bb60_v1.kicad_pcb]
2026-04-06 Added Ai03 Library, fixed stab positions
    [Gateron-KS33-Socket.step, Kailh-Choc-Socket-CPG135001S30.step, MX-Hotswap-Socket.step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]
2026-04-06 minor changes
    [bb60_v1.kicad_pcb]
2026-04-06 rearranging pcb
    [bb60_v1.kicad_pcb]
2026-04-07 new traces made
    [bb60_v1.kicad_pcb]
2026-04-09 added velvet pro pcb outline
    [Velvet_Pro_PCB_outline.DXF]
2026-04-09 added pcb outline to pcb
    [bb60_v1.kicad_pcb]
2026-04-09 Routed traces columns 7-11
    [bb60_v1.kicad_pcb, bb60_v1.kicad_sch]
2026-04-10 test export fab files
    [bb60_v1.kicad_pcb]
2026-04-12 finished row/column traces
    [bb60_v1.kicad_pcb, bb60_v1.kicad_sch]
2026-04-12 Rerouted everything
    [bb60_v1.kicad_pcb, bb60_v1.kicad_sch]
2026-04-12 updated pushbuttons
    [bb60_v1.kicad_pcb]
2026-04-13 idk what i changed here
    [bb60_v1.kicad_sch]
2026-04-13 added ground plane, completed power traces
    just need bootloader and reset buttons to be routed next, also increase trace width for power cables
    [bb60_v1.kicad_pcb]
2026-04-14 finished wiring everything
    ratsnest gone
    [bb60_v1.kicad_pcb]
2026-04-14 Final changes
    [bb60_v1.kicad_pcb, bb60_v1.kicad_sch]
2026-04-14 added files to new folder
    [Plate_File_No_Flex_Cuts (1).dxf, Plate_File_with_Flex_Cuts (1).dxf, Velvet_Pro_PCB_outline.DXF]
2026-04-14 Rename KiCad project to VP_Solder and clean up production files
    [VP_Solder.kicad_pcb, VP_Solder.kicad_sch]
2026-04-14 Add initial README with PCB specifications
2026-04-17 Added split backspace
    [VP_Solder.kicad_pcb, VP_Solder.kicad_sch]
2026-04-17 Added testpoints
    [VP_Solder.kicad_pcb, VP_Solder.kicad_sch]
2026-04-17 ran drc, fixed some tracing errors
    [VP_Solder.kicad_pcb]
2026-04-17 fixed DRC errors
    [VP_Solder.kicad_pcb, VP_Solder.kicad_sch]
2026-04-17 Small changes to silkscreen
    [VP_Solder.kicad_pcb]
2026-04-17 Changed testpoint names
    [VP_Solder.kicad_pcb, VP_Solder.kicad_sch]
2026-04-17 Changed silkscreen
    [VP_Solder.kicad_sch]
2026-04-18 final changes, drc fixes
    [VP_Solder.kicad_pcb, VP_Solder.kicad_sch, Velvet_Pro_PCB_outline_v2.DXF]
2026-07-26 added new footprints to custom library
    [VP_Solder.kicad_pcb]
2026-07-26 added 3d models, license and notice
    [HS_CPG151101S11_MX.step, HS_KS-2P02B01-01_MX.step, LED_MHT151RGBCT.step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]
2026-07-26 updated schematic + pcb with new custom library symbols and footprints
    [VP_Solder.kicad_pcb, VP_Solder.kicad_sch]
2026-07-26 removed old libraries, updated gitignore
    [Gateron-KS33-Socket.step, Kailh-Choc-Socket-CPG135001S30.step, MX-Hotswap-Socket.step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]
2026-07-27 silkscreen changes, added extra diodes, changed to official vp pcb outline
    [VP PCB DXF.dxf, VP_Solder.kicad_pcb, VP_Solder.kicad_sch]
2026-07-27 final touches to pcb, created production files
    [VP_Solder.kicad_pcb, Velvet_Pro_PCB_outline (outdated).DXF]
2026-07-27 updated readme, updated plate and cutout files
    [Plate_File_No_Flex_Cuts.dxf, Plate_File_with_Flex_Cuts.dxf, VP PCB DXF.dxf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]
2026-07-27 Final small tweaks
    [VP_Solder.kicad_pcb]
2026-07-27 minor final tweaks
    [VP_Solder.kicad_pcb]
2026-07-27 folder organizational changes
    [Plate_File_No_Flex_Cuts.dxf, Plate_File_with_Flex_Cuts.dxf, Velvet_Pro_PCB_outline.dxf]
2026-07-27 updated gitignore to allow production csv files to pass
    [bom.csv, positions.csv]
2026-07-27 Revise JLCPCB ordering instructions in README
    Updated instructions for ordering PCBs from JLCPCB, including assembly options and file uploads.
2026-07-27 Update README with ordering instructions and cleanup
    Removed redundant instruction for soldering components and added details for ordering parts from JLCPCB.
2026-07-27 Update README with alternative JLCPCB part IDs
    Added alternative JLCPCB part IDs for components in the BOM.
2026-07-27 Update README with JLCPCB ordering instructions
    Added images and detailed instructions for ordering from JLCPCB with assembly.
2026-07-27 Clarify U1 orientation in JLC assembly instructions
    Added clarification about component orientation for U1.
2026-07-27 Revise PCB assembly instructions in README
    Updated instructions for PCB assembly and component confirmation steps in README.
